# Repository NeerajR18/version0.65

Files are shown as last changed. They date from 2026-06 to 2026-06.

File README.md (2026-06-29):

# version0.65

version0.65 is an almost 65% keyboard. It is a bluetooth keyboard, using the SuperMini nRF52840 board, which is pin compatible with the nice!nano v2.
It has a built in battery along with a On/Off switch.

The keyboard is hotswap, with gateron hotswap sockets and Gateron Blue switches.

The PCB was designed in KiCad and the case was designed in Autodesk Fusion. The footprints for the switches have been taken from the marbastlib library - https://github.com/ebastler/marbastlib

This Keyboard was made for Hack Club KEEB.

Note: This is still a WIP. Please copy at your own risk.

## Repository Guide
```
version1/
|── PCB/
|   |── version0.65.kicad_pro
|   |── version0.65.kicad_pcb
|   |── version0.65.kicad_sch
|   └── fp-lib-table
|
|── CAD/
|   |── Base/
|   |   |── version0.65-base-left.step
|   |   |── version0.65-base-middle.step
|   |   └── version0.65-base-right.step
|   |   
|   |──── Top/
|   |     |── version0.65-plate-left.step
|   |     └── version0.65-plate-right.step
|   |
|   |── version0.65-assembly.step
|   └── version0.65.f3z
| 
|── Production/   
|    |── gerbers.zip/
|    |
|    |── STL Files/
|    |   |─── version0.65-base/
|    |   |    |── version0.65-base-left.stl
|    |   |    |── version0.65-base-middle.stl
|    |   |    └── version0.65-base-right.stl
|    |   |
|    |   └─── version0.65-plate/
|    |        |── version0.65-plate-left.stl
|    |        └── version0.65-plate-right.stl
|    |
|    └── STEP Files/
|           |─── version0.65-base/
|           |      |── version0.65-base-left.step
|           |      |── version0.65-base-middle.step
|           |      └── version0.65-base-right.step
|           |
|           └──── version0.65-plate/
|                   |── version0.65-plate-left.step
|                   └── version0.65-plate-right.step
|
|── Assets/
|    |── Keycaps/
|    |── MX Switch/
|    └── nice!nano/
|
|── Firmware/
|
|── BOM.csv
|── journal.md
└── README.md
```

## Schematic
##### Overall Schematic


## PCB
##### PCB Front without GND Plane


##### PCB Front with GND Plane


##### PCB Back without GND Plane


##### PCB Back with GND Plane


## CAD
The case has been split to accomodate 3D printing. The plates and base have small pegs and holes for assembly.

#### Full Assembly
##### Top View


#####  Side View


#### Top Plate
##### Top View


#####  Side View


#### Base
##### Top View


#####  Side View

 
## Firmware
version0.65 uses ZMK firmare. While the firmware has not been tested IRL, it can be found in a separate repository.

Firmware repository- https://github.com/NeerajR18/zmk-config-version0.65

## Bill of Materials
| Part Name | Quantity | Unit Price (USD) | Ext. Price (USD) | Link |
|---|---:|---:|---:|---|
| nRF52840 Development Board (Compatible with nice!nano) | 1 | 8.00 | 8.00 | https://robu.in/product/promicro-nrf52840-development-board/ |
| Gradient Keycaps | 1 | 13.66 | 13.66 | https://stackskb.com/store/veekos-gradient-keycaps-cherry-profile-135-keys/ |
| Gateron Hotswap Sockets | 66 | 0.11 | 7.00 | https://stackskb.com/store/gateron-hotswap-sockets/ |
| Gateron G Pro 3.0 Switch (Pack of 10) | 7 | 2.10 | 14.71 | https://meckeys.com/shop/accessories/keyboard-accessories/key-switches/gateron-g-pro-3-0-switch/ |
| OS102011MA1QN1 | 1 | 0.38 | 0.38 | https://robu.in/product/os102011ma1qn1-ck-100ma-single-pole-double-throw-spdt-12v-10000-times-plugin-slide-switches-rohs/ |
| S2B-PH-SM4-TB | 1 | 0.42 | 0.42 | https://robu.in/product/s2b-ph-sm4-tblfsn-jst-1x2p-2p-ph-tin-2-25%E2%84%8385%E2%84%83-2a-1-2mm-copper-alloy-horizontal-attachment-smdp2mmsurface-mount%EF%BC%8Cright-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 |
| 1N4148W-T4 | 66 | 0.015 | 0.99 | https://sharvielectronics.com/product/1n4148w-t4-high-speed-fast-switching-diode-sod-123-package/ |
| YY503040-JST-PH | 1 | 2.31 | 2.31 | https://sharvielectronics.com/product/3-7v-1100mah-lipo-rechargeable-battery-with-jst-ph-2mm-connector/ |
| PCB from Robu | 5 | 8.83 | 44.28 | https://robu.in/ |
| Cherry Stabilizer Set (GEON AND C3) | 1 | 7.36 | 7.36 | https://neomacro.in/products/cherry-stabilizer-set-geon-and-c3?_pos=3&_sid=9a6134911&_ss=r |
| M3 Heatset Insert | 20 | 0.025 | 0.50 | https://onlyscrews.in/products/m3-x-3mm-brass-threaded-inserts |
| M3 × 16mm Screws | 20 | 0.023 | 0.46 | https://onlyscrews.in/products/hex-allen-csk-m3-x-16-screw-pack-of-20 |
| Shipping charges |-| - | 7 | - |
| **Total** |  |  | **107.07** |  |

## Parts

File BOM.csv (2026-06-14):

Part Name | Quantity | Unit Price(USD) | Ext. Price (USD) | Link
nRF52840 Development Board(Compatible with nice!nano) | 1 | 8 | 8 | https://robu.in/product/promicro-nrf52840-development-board/
Gradient Keycaps | 1 | 13.66 | 13.66 | https://stackskb.com/store/veekos-gradient-keycaps-cherry-profile-135-keys/
Gateron Hotswap Sockets | 66 | 0.11 | 7 | https://stackskb.com/store/gateron-hotswap-sockets/
Gateron G Pro 3.0 Switch (Pack of 10) | 7 | 2.1 | 14.71 | https://meckeys.com/shop/accessories/keyboard-accessories/key-switches/gateron-g-pro-3-0-switch/
OS102011MA1QN1 | 1 | 0.38 | 0.38 | https://robu.in/product/os102011ma1qn1-ck-100ma-single-pole-double-throw-spdt-12v-10000-times-plugin-slide-switches-rohs/
S2B-PH-SM4-TB | 1 | 0.42 | 0.42 | https://robu.in/product/s2b-ph-sm4-tblfsn-jst-1x2p-2p-ph-tin-2-25%e2%84%8385%e2%84%83-2a-1-2mm-copper-alloy-horizontal-attachment-smdp2mmsurface-mount%ef%bc%8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
1N4148W-T4 | 66 | 0.015 | 0.99 | https://sharvielectronics.com/product/1n4148w-t4-high-speed-fast-switching-diode-sod-123-package/
Stabilizers set | 1 | 7.36 | 7.36 | https://neomacro.in/products/cherry-stabilizer-set-geon-and-c3?_pos=3&_sid=9a6134911&_ss=r
M3x3mm Heatset Inserts | 20 | 0.025 | 0.5 | https://onlyscrews.in/products/m3-x-3mm-brass-threaded-inserts
M3x16 mm Screws | 20 | 0.023 | 0.046 | https://onlyscrews.in/products/hex-allen-csk-m3-x-16-screw-pack-of-20
YY503040-JST-PH | 1 | 2.31 | 2.31 | https://sharvielectronics.com/product/3-7v-1100mah-lipo-rechargeable-battery-with-jst-ph-2mm-connector/
PCB from robu | 5 | 8.05 | 48.35 | https://robu.in/
Total |  |  | 103.726

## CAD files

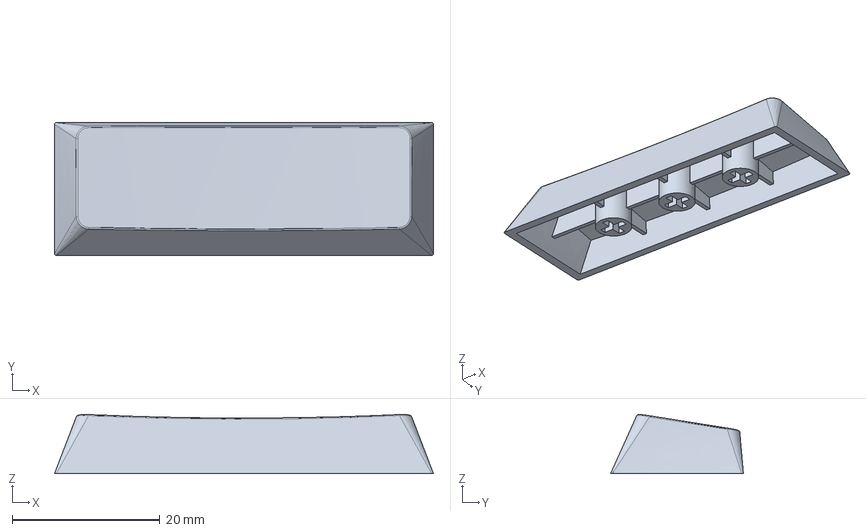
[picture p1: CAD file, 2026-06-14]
Assets/Keycaps/Rshift.step
51.3 x 18.0 x 8.00 mm

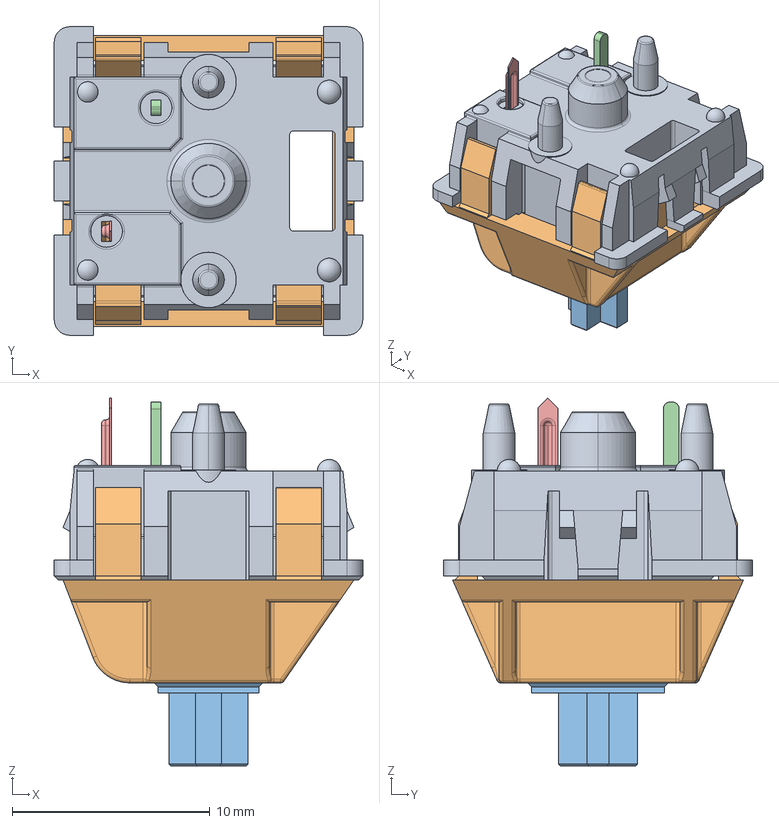
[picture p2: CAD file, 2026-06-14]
Assets/MX Switch/MX_switch.stp
15.6 x 15.6 x 18.6 mm
MX_DOWN
MX_UP
UP_MX
MX_PIN
MX_SPRING
MX_CLICK

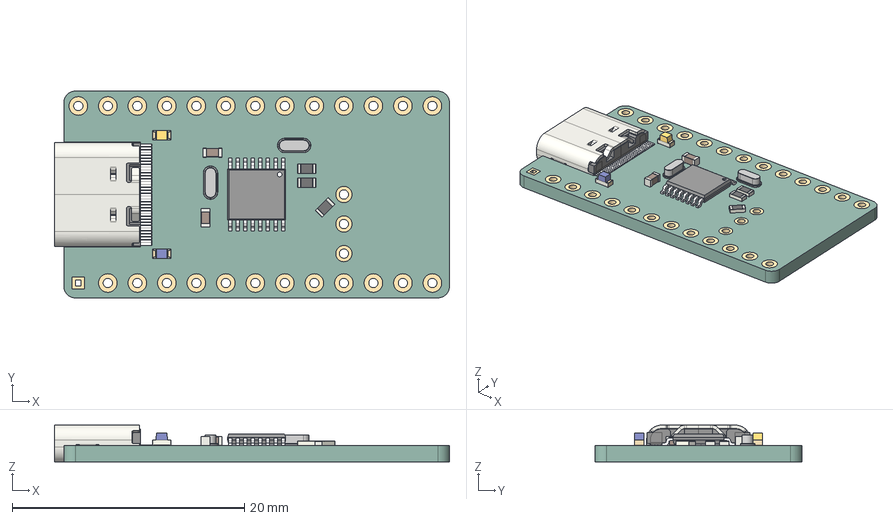
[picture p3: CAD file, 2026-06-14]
Assets/nice!nano/nice!nano v2.step
34.0 x 17.8 x 3.16 mm
nice!nano v1.0_1
USB_C_Receptacle_16P_TopMnt_Horizontal_GCT_USB4105-xx-A
USB_C_Receptacle_16P_TopMnt_Horizontal_GCT_USB4105-xx-A001
USB_C_Receptacle_16P_TopMnt_Horizontal_GCT_USB4105-xx-A002
USB_C_Receptacle_16P_TopMnt_Horizontal_GCT_USB4105-xx-A003
USB_C_Receptacle_16P_TopMnt_Horizontal_GCT_USB4105-xx-A004
USB_C_Receptacle_16P_TopMnt_Horizontal_GCT_USB4105-xx-A005
USB_C_Receptacle_16P_TopMnt_Horizontal_GCT_USB4105-xx-A006
USB_C_Receptacle_16P_TopMnt_Horizontal_GCT_USB4105-xx-A007
USB_C_Receptacle_16P_TopMnt_Horizontal_GCT_USB4105-xx-A008
USB_C_Receptacle_16P_TopMnt_Horizontal_GCT_USB4105-xx-A009
USB_C_Receptacle_16P_TopMnt_Horizontal_GCT_USB4105-xx-A010
USB_C_Receptacle_16P_TopMnt_Horizontal_GCT_USB4105-xx-A011
USB_C_Receptacle_16P_TopMnt_Horizontal_GCT_USB4105-xx-A012
USB_C_Receptacle_16P_TopMnt_Horizontal_GCT_USB4105-xx-A013
USB_C_Receptacle_16P_TopMnt_Horizontal_GCT_USB4105-xx-A014
USB_C_Receptacle_16P_TopMnt_Horizontal_GCT_USB4105-xx-A015
USB_C_Receptacle_16P_TopMnt_Horizontal_GCT_USB4105-xx-A016
USB_C_Receptacle_16P_TopMnt_Horizontal_GCT_USB4105-xx-A017
USB_C_Receptacle_16P_TopMnt_Horizontal_GCT_USB4105-xx-A018
USB_C_Receptacle_16P_TopMnt_Horizontal_GCT_USB4105-xx-A019
USB_C_Receptacle_16P_TopMnt_Horizontal_GCT_USB4105-xx-A020
USB_C_Receptacle_16P_TopMnt_Horizontal_GCT_USB4105-xx-A021
USB_C_Receptacle_16P_TopMnt_Horizontal_GCT_USB4105-xx-A022
USB_C_Receptacle_16P_TopMnt_Horizontal_GCT_USB4105-xx-A023
USB_C_Receptacle_16P_TopMnt_Horizontal_GCT_USB4105-xx-A024
USB_C_Receptacle_16P_TopMnt_Horizontal_GCT_USB4105-xx-A025
USB_C_Receptacle_16P_TopMnt_Horizontal_GCT_USB4105-xx-A026
USB_C_Receptacle_16P_TopMnt_Horizontal_GCT_USB4105-xx-A027
USB_C_Receptacle_16P_TopMnt_Horizontal_GCT_USB4105-xx-A028
USB_C_Receptacle_16P_TopMnt_Horizontal_GCT_USB4105-xx-A029
USB_C_Receptacle_16P_TopMnt_Horizontal_GCT_USB4105-xx-A030
USB_C_Receptacle_16P_TopMnt_Horizontal_GCT_USB4105-xx-A031
USB_C_Receptacle_16P_TopMnt_Horizontal_GCT_USB4105-xx-A032
USB_C_Receptacle_16P_TopMnt_Horizontal_GCT_USB4105-xx-A033
USB_C_Receptacle_16P_TopMnt_Horizontal_GCT_USB4105-xx-A034
USB_C_Receptacle_16P_TopMnt_Horizontal_GCT_USB4105-xx-A035
Pin9
Pin10
Pin12
Pin11
Pin13
Pin14
Pin15
Pin16
Pin8
Pin7
Pin6
Pin5
Pin4
Pin3
Pin2
Pin1
LED_0603_1608Metric_ON
C_0603_1608Metric x 2
LED_0603_1608Metric_ON_1
Crystal Oscillator x 2
R_0603_1608Metric x 4

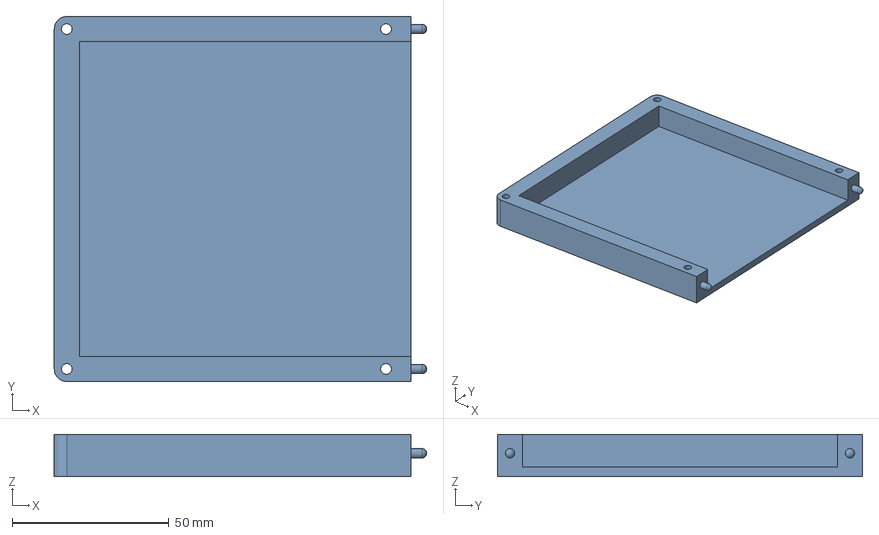
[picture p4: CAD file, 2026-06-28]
CAD/Base/version0.65-base-left.step
118.8 x 116.4 x 13.4 mm

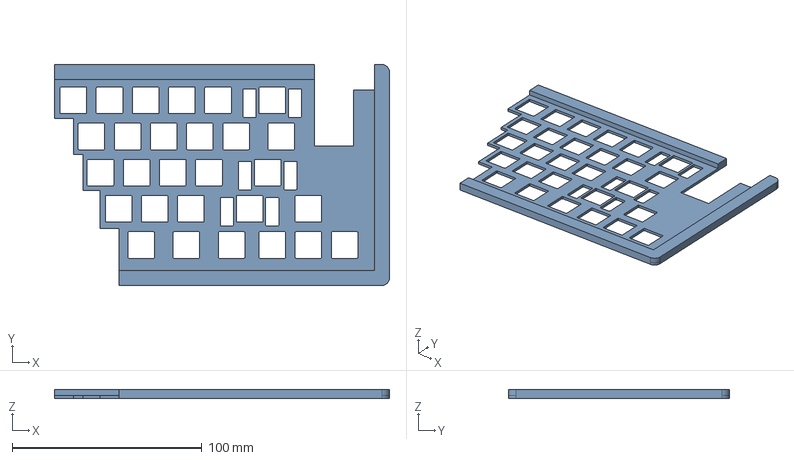
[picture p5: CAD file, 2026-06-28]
CAD/Plate/version0.65-plate-right.step
176.5 x 116.4 x 4.50 mm

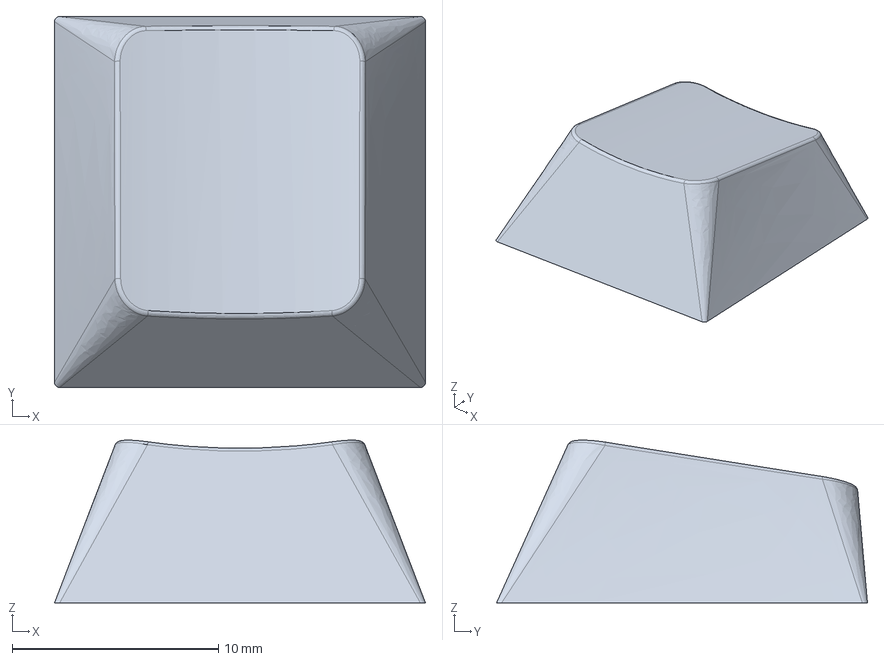
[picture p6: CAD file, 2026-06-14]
Assets/Keycaps/Qwerty.step
18.0 x 18.0 x 7.90 mm

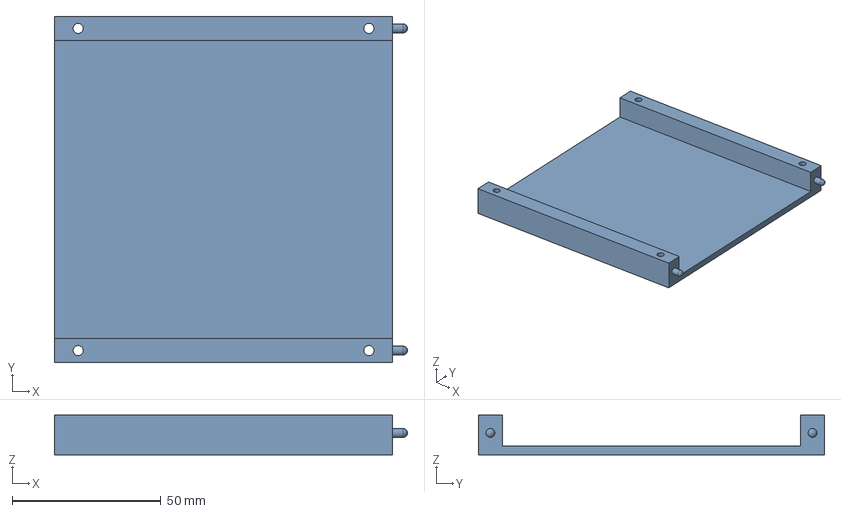
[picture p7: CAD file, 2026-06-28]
CAD/Base/version0.65-base-middle.step
118.8 x 116.4 x 13.4 mm

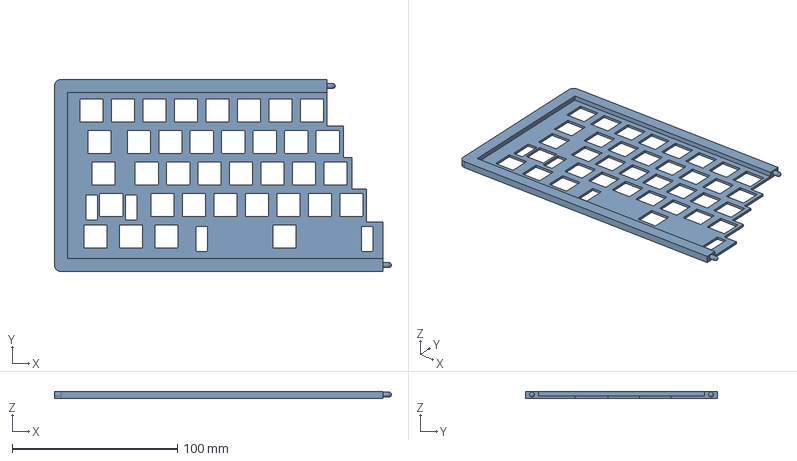
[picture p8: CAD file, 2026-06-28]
CAD/Plate/version0.65-plate-left.step
204.0 x 116.4 x 4.50 mm

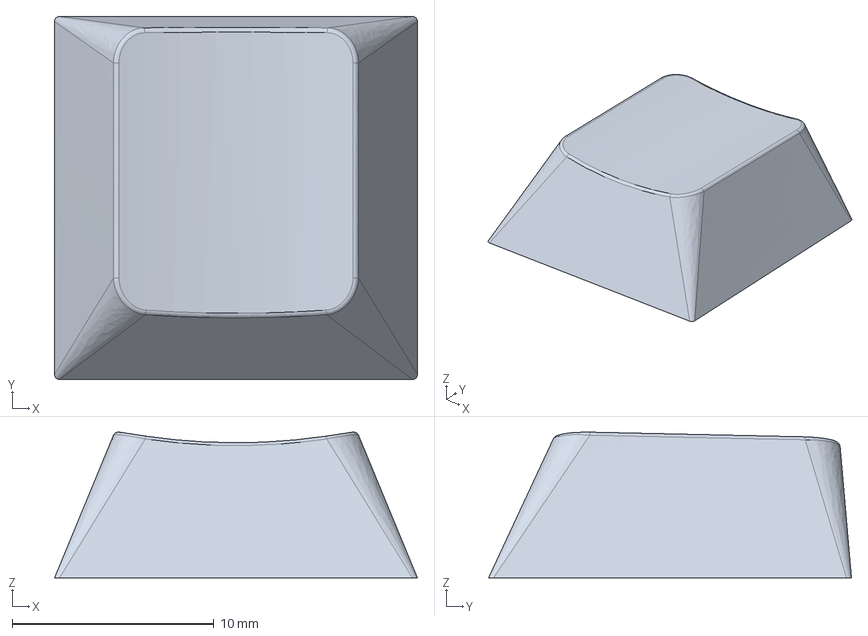
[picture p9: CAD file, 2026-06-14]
Assets/Keycaps/ROW_1_Numbers.step
18.0 x 18.0 x 7.23 mm

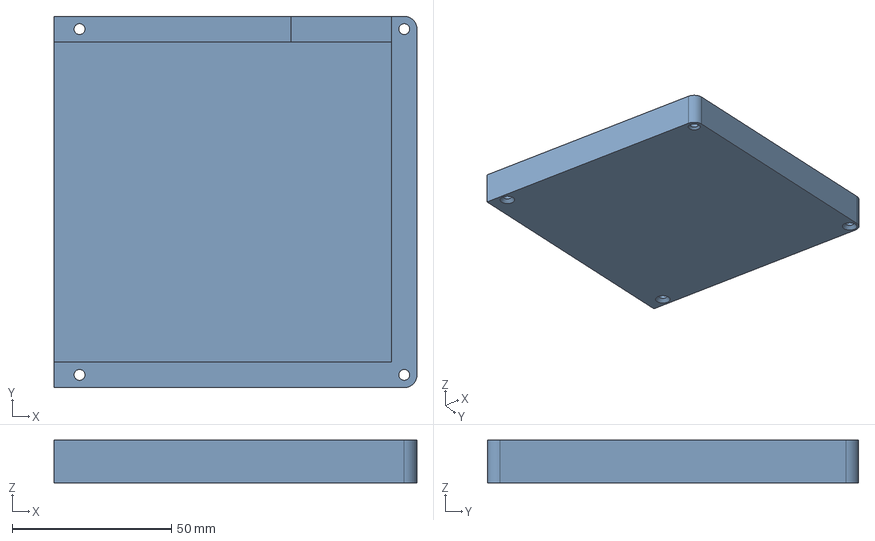
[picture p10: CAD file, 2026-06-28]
CAD/Base/version0.65-base-right.step
113.8 x 116.4 x 13.4 mm

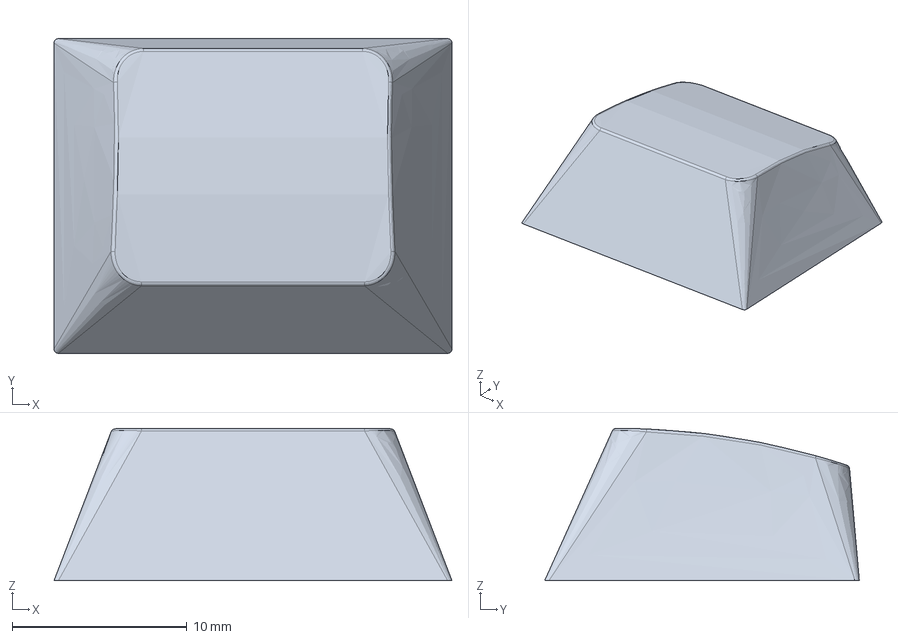
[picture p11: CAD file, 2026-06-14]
Assets/Keycaps/Bottom_row1u25.step
22.8 x 18.0 x 8.70 mm

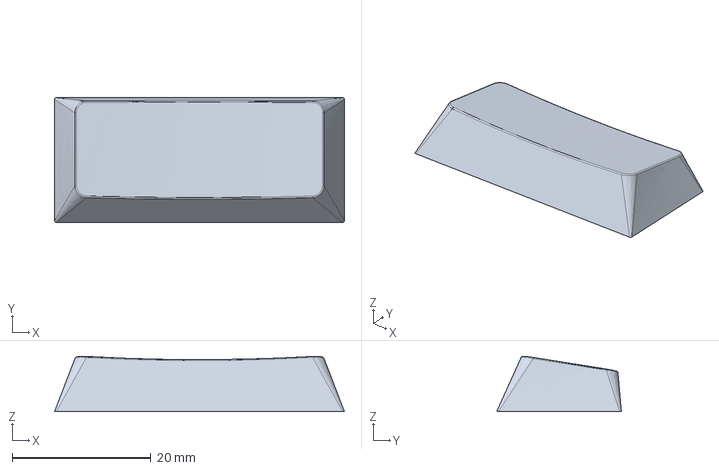
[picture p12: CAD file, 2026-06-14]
Assets/Keycaps/Enter_Lshift.step
41.8 x 18.0 x 7.99 mm

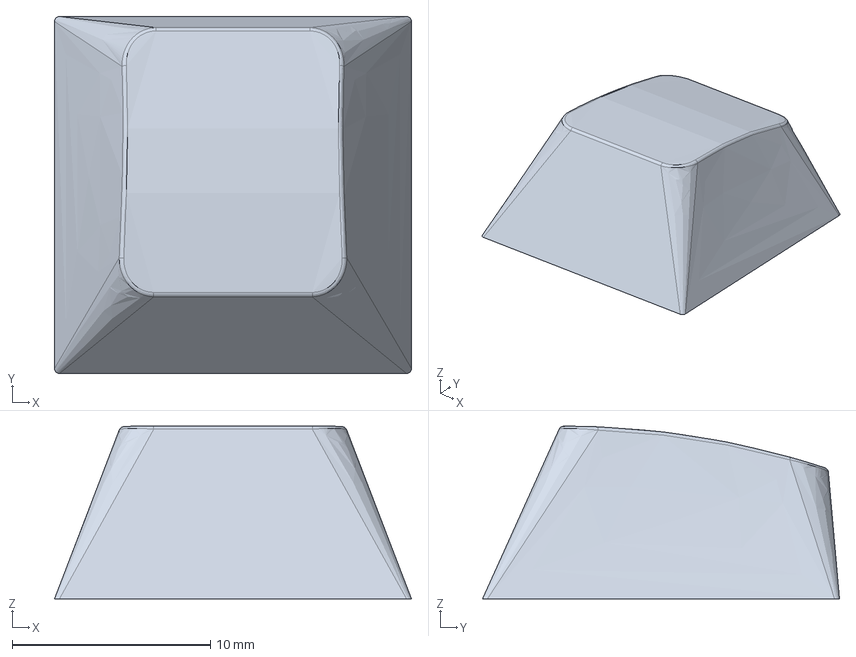
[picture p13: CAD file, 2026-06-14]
Assets/Keycaps/Bottom_row1u.step
18.0 x 18.0 x 8.70 mm

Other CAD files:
Assets/Keycaps/Back_sp.step
Assets/Keycaps/Backsp.step
Assets/Keycaps/Caps.step
Assets/Keycaps/ESC_and_Function_keys.step
Assets/Keycaps/Space_bar.step
Assets/Keycaps/Tab_key.step
Assets/Keycaps/middle_row.step
Production/STL Files/Base/version0.65-base-left.stl
Production/STL Files/Base/version0.65-base-middle.stl
Production/STL Files/Base/version0.65-base-right.stl
Production/STL Files/Plate/version0.65-plate-left.stl
Production/STL Files/Plate/version0.65-plate-right.stl

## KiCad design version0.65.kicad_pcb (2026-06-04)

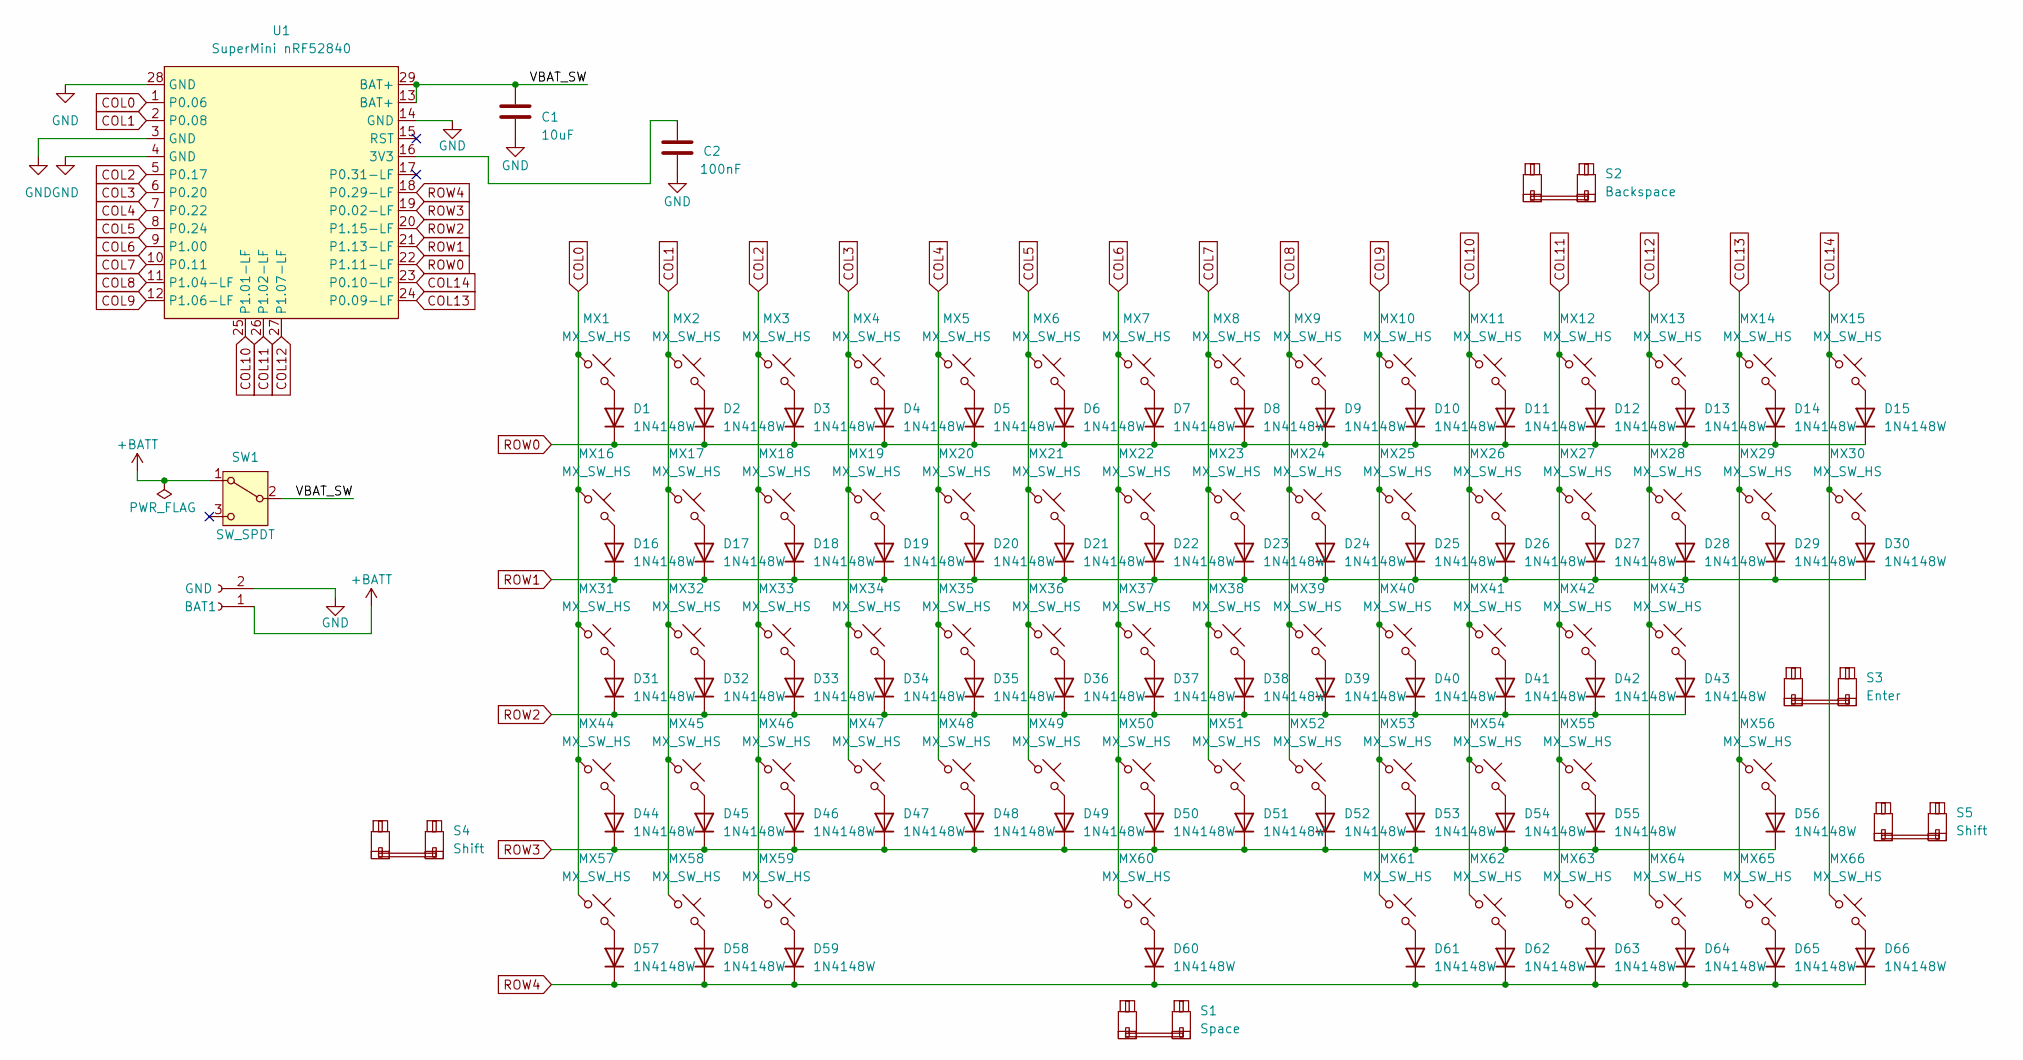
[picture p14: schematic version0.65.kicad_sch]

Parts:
BAT1: GND; JST_PH_S2B-PH-K_1x02_P2.00mm_Horizontal
C1: 10uF; C_0805_2012Metric
C2: 100nF; C_0805_2012Metric
D1, D2, D3, D4, D5, D6, D7, D8, D9, D10, D11, D12, D13, D14, D15, D16, D17, D18, D19, D20, D21, D22, D23, D24, D25, D26, D27, D28, D29, D30, D31, D32, D33, D34, D35, D36, D37, D38, D39, D40, D41, D42, D43, D44, D45, D46, D47, D48, D49, D50, D51, D52, D53, D54, D55, D56, D57, D58, D59, D60, D61, D62, D63, D64, D65, D66: 1N4148W; D_SOD-123
MX1, MX2, MX3, MX4, MX5, MX6, MX7, MX8, MX9, MX10, MX11, MX12, MX13, MX14, MX15, MX17, MX18, MX19, MX20, MX21, MX22, MX23, MX24, MX25, MX26, MX27, MX28, MX30, MX32, MX33, MX34, MX35, MX36, MX37, MX38, MX39, MX40, MX41, MX42, MX43, MX44, MX45, MX46, MX47, MX48, MX49, MX50, MX51, MX52, MX53, MX54, MX55, MX56, MX58, MX60, MX64, MX65, MX66: MX_SW_HS; SW_MX_HS_KS-2P02B01-01_1u
MX16, MX29: MX_SW_HS; SW_MX_HS_KS-2P02B01-01_1.5u
MX31: MX_SW_HS; SW_MX_HS_KS-2P02B01-01_1.75u
MX57, MX59, MX61, MX62, MX63: MX_SW_HS; SW_MX_HS_KS-2P02B01-01_1.25u
S1: Space; STAB_MX_P_6.25u
S2: Backspace; STAB_MX_2u
S3: Enter; STAB_MX_2.25u
S4, S5: Shift; STAB_MX_2.25u
SW1: SW_SPDT; SW_Slide_SPDT_Angled_CK_OS102011MA1Q
U1: SuperMini nRF52840; SuperMini_nRF52840_AH_USBup

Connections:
+BATT: BAT1.1, SW1.1 (A)
/VBAT_SW: C1.2, SW1.2 (B), U1.13 (BAT+), U1.29 (BAT+)
COL0: MX1.1, MX16.1, MX31.1, MX44.1, MX57.1, U1.1 (P0.06)
COL1: MX2.1, MX17.1, MX32.1, MX45.1, MX58.1, U1.2 (P0.08)
COL2: MX3.1, MX18.1, MX33.1, MX46.1, MX59.1, U1.5 (P0.17)
COL3: MX4.1, MX19.1, MX34.1, MX47.1, U1.6 (P0.20)
COL4: MX5.1, MX20.1, MX35.1, MX48.1, U1.7 (P0.22)
COL5: MX6.1, MX21.1, MX36.1, MX49.1, U1.8 (P0.24)
COL6: MX7.1, MX22.1, MX37.1, MX50.1, MX60.1, U1.9 (P1.00)
COL7: MX8.1, MX23.1, MX38.1, MX51.1, U1.10 (P0.11)
COL8: MX9.1, MX24.1, MX39.1, MX52.1, U1.11 (P1.04-LF)
COL9: MX10.1, MX25.1, MX40.1, MX53.1, MX61.1, U1.12 (P1.06-LF)
COL10: MX11.1, MX26.1, MX41.1, MX54.1, MX62.1, U1.25 (P1.01-LF)
COL11: MX12.1, MX27.1, MX42.1, MX55.1, MX63.1, U1.26 (P1.02-LF)
COL12: MX13.1, MX28.1, MX43.1, MX64.1, U1.27 (P1.07-LF)
COL13: MX14.1, MX29.1, MX56.1, MX65.1, U1.24 (P0.09-LF)
COL14: MX15.1, MX30.1, MX66.1, U1.23 (P0.10-LF)
GND: BAT1.2, C1.1, C2.1, U1.3 (GND), U1.4 (GND), U1.14 (GND), U1.28 (GND)
unnamed: D1.2 (A), MX1.2
unnamed: D2.2 (A), MX2.2
unnamed: D3.2 (A), MX3.2
unnamed: D4.2 (A), MX4.2
unnamed: D5.2 (A), MX5.2
unnamed: D6.2 (A), MX6.2
unnamed: D7.2 (A), MX7.2
unnamed: D8.2 (A), MX8.2
unnamed: D9.2 (A), MX9.2
unnamed: D10.2 (A), MX10.2
unnamed: D11.2 (A), MX11.2
unnamed: D12.2 (A), MX12.2
unnamed: D13.2 (A), MX13.2
unnamed: D14.2 (A), MX14.2
unnamed: D15.2 (A), MX15.2
unnamed: D16.2 (A), MX16.2
unnamed: D17.2 (A), MX17.2
unnamed: D18.2 (A), MX18.2
unnamed: D19.2 (A), MX19.2
unnamed: D20.2 (A), MX20.2
unnamed: D21.2 (A), MX21.2
unnamed: D22.2 (A), MX22.2
unnamed: D23.2 (A), MX23.2
unnamed: D24.2 (A), MX24.2
unnamed: D25.2 (A), MX25.2
unnamed: D26.2 (A), MX26.2
unnamed: D27.2 (A), MX27.2
unnamed: D28.2 (A), MX28.2
unnamed: D29.2 (A), MX29.2
unnamed: D30.2 (A), MX30.2
unnamed: D31.2 (A), MX31.2
unnamed: D32.2 (A), MX32.2
unnamed: D33.2 (A), MX33.2
unnamed: D34.2 (A), MX34.2
unnamed: D35.2 (A), MX35.2
unnamed: D36.2 (A), MX36.2
unnamed: D37.2 (A), MX37.2
unnamed: D38.2 (A), MX38.2
unnamed: D39.2 (A), MX39.2
unnamed: D40.2 (A), MX40.2
unnamed: D41.2 (A), MX41.2
unnamed: D42.2 (A), MX42.2
unnamed: D43.2 (A), MX43.2
unnamed: D44.2 (A), MX44.2
unnamed: D45.2 (A), MX45.2
unnamed: D46.2 (A), MX46.2
unnamed: D47.2 (A), MX47.2
unnamed: D48.2 (A), MX48.2
unnamed: D49.2 (A), MX49.2
unnamed: D50.2 (A), MX50.2
unnamed: D51.2 (A), MX51.2
unnamed: D52.2 (A), MX52.2
unnamed: D53.2 (A), MX53.2
unnamed: D54.2 (A), MX54.2
unnamed: D55.2 (A), MX55.2
unnamed: D56.2 (A), MX56.2
unnamed: D57.2 (A), MX57.2
unnamed: D58.2 (A), MX58.2
unnamed: D59.2 (A), MX59.2
unnamed: D60.2 (A), MX60.2
unnamed: D61.2 (A), MX61.2
unnamed: D62.2 (A), MX62.2
unnamed: D63.2 (A), MX63.2
unnamed: D64.2 (A), MX64.2
unnamed: D65.2 (A), MX65.2
unnamed: D66.2 (A), MX66.2
unnamed: C2.2, U1.16 (3V3)
ROW0: D1.1 (K), D2.1 (K), D3.1 (K), D4.1 (K), D5.1 (K), D6.1 (K), D7.1 (K), D8.1 (K), D9.1 (K), D10.1 (K), D11.1 (K), D12.1 (K), D13.1 (K), D14.1 (K), D15.1 (K), U1.22 (P1.11-LF)
ROW1: D16.1 (K), D17.1 (K), D18.1 (K), D19.1 (K), D20.1 (K), D21.1 (K), D22.1 (K), D23.1 (K), D24.1 (K), D25.1 (K), D26.1 (K), D27.1 (K), D28.1 (K), D29.1 (K), D30.1 (K), U1.21 (P1.13-LF)
ROW2: D31.1 (K), D32.1 (K), D33.1 (K), D34.1 (K), D35.1 (K), D36.1 (K), D37.1 (K), D38.1 (K), D39.1 (K), D40.1 (K), D41.1 (K), D42.1 (K), D43.1 (K), U1.20 (P1.15-LF)
ROW3: D44.1 (K), D45.1 (K), D46.1 (K), D47.1 (K), D48.1 (K), D49.1 (K), D50.1 (K), D51.1 (K), D52.1 (K), D53.1 (K), D54.1 (K), D55.1 (K), D56.1 (K), U1.19 (P0.02-LF)
ROW4: D57.1 (K), D58.1 (K), D59.1 (K), D60.1 (K), D61.1 (K), D62.1 (K), D63.1 (K), D64.1 (K), D65.1 (K), D66.1 (K), U1.18 (P0.29-LF)

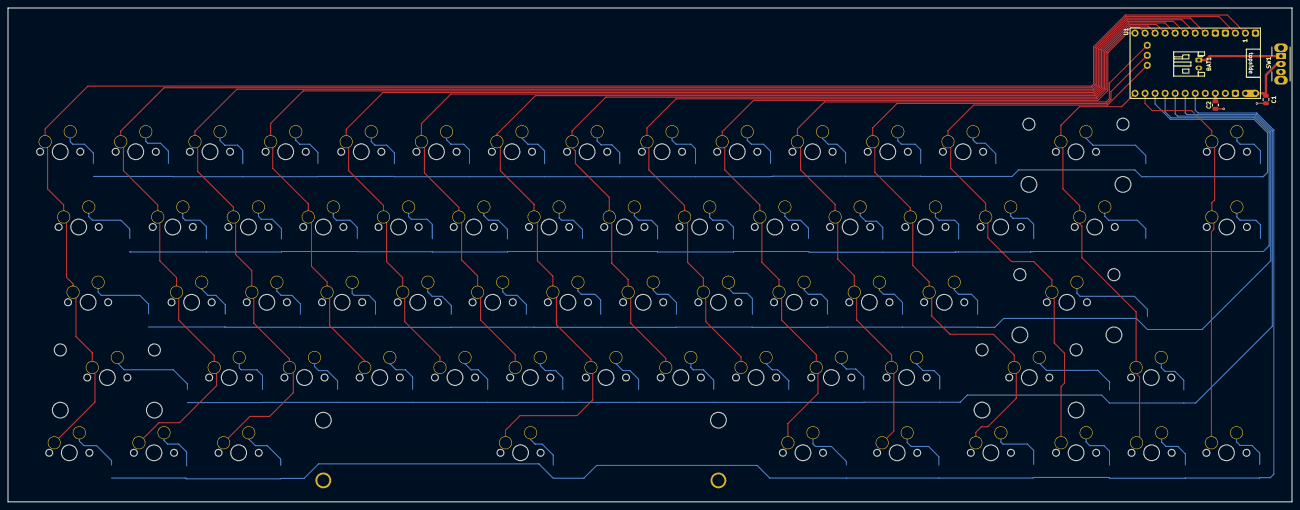
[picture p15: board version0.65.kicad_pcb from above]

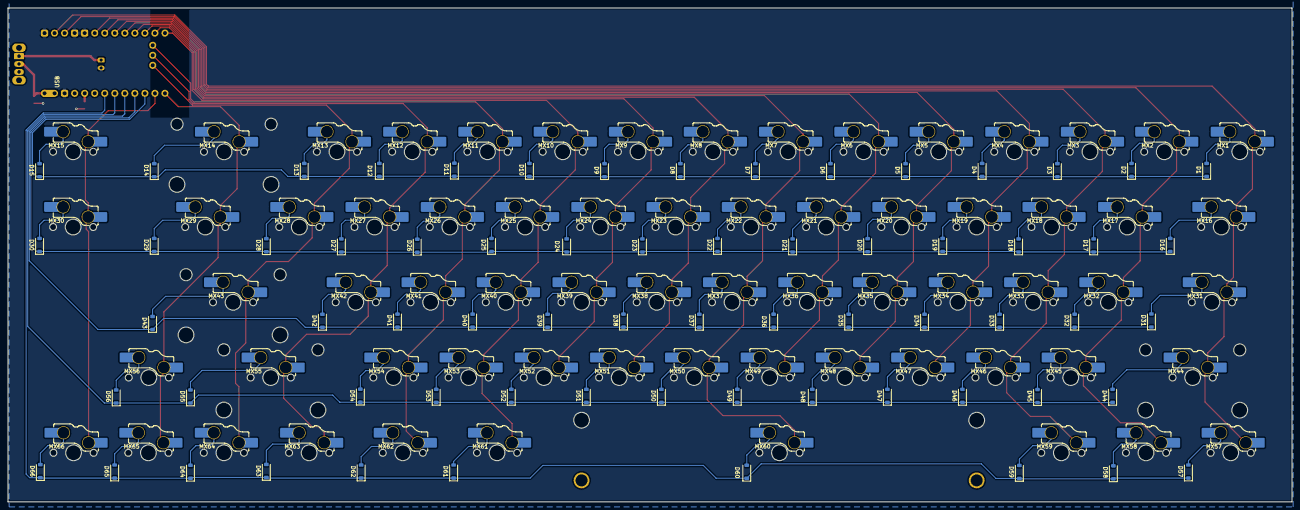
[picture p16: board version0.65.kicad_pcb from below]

Board: 2 copper layers, 325.0 x 125.0 mm, 142 parts (133 on the bottom side), 90 nets.

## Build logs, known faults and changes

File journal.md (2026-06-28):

## Journal 1

I started my first project for KEEB!

I have decided to make a Leopold 660m layout keyboard, a wireless keyboard with the Supermini nrF52840.
Now, I had to find some reference keyboards since I have not used the Supermini or made a wireless keyboard.
I found a great project on a 65% keyboard. It uses through hole components but that is not a big problem, since I know how the matrix and connections work. I only needed to refer to the battery connections and the GPIOs I can use.
This is the reference I found : https://github.com/RafaelCasamaximo/voidPointer
This is a really great project in my opinion and since it was already built, it was even more helpful.
All I had to do now was make the schematic, assign the footprints and start building!

I like minimal keyboards, so I have only the keys, the supermini and a sandwich mount case (or integrated plate) case.
The repo I was referring to also had a slider switch, which was pretty cool!
I added all the components, and placed them according to the reference.
I also had fewer switches compared to the reference, so I made some changes to the matrix.

While I do not have all the images of my schematic building process, I do have the full schematic ready. 
I am using Gateron hotswap sockets for this keyboard, along with SOD-123 diodes. All my footprints are from the marbastlib library(along with supermini)



I assigned footprints and now I have to place all the components.
For this, I used the grid from the guide,and the generated plate from the ai03 plate generator.

#### Time taken - around 2 hrs to make the schematic and place all switches.

## Journal 2

Today, I did the entire PCB layout!
This is my favourite part of the entire PCB design because it really gets me thinking because of constant changes to the layout and I get to crashout.



I had already laid down the keys, so all I had to do was routing. I had also not laid out the diodes and added the stabilizers correctly. The Leopold does not have a very long right shift so, I had to change those, and also while updating the schematic, some of the footprints were changed only in the PCB editor, which caused it to change.
I fixed everything, then I decided that the top right of the PCB is the best placed for the supermini. It increases the height a bit, but yes, that is inevitable imo but it is also almost equivalent to the size of the Leopold 660m(with case but yes since this is custom, I have my say ;D )

This is how the keyboard looked after I placed the diodes.



Now, routing is always a challenge with the matrix, as it can be optimised in such a way that there is no need for vias and it looks clean.
I had to change the pins many times while routing this.
I routed all the diodes first. I have my own way of routing diodes so that it passes with some gap with the holes.
Sure, the normal way is fine but there is always a risk.



Here are some images of the PCB routing process-



This was the first routing layout I did. The GPIOs were unreachable and the traces were too far apart, increasing the width of the PCB.
I changed this.

I changed my pins a few more times and reached to this layout. All that was left were the ground connections and battery connections.
I added the battery connections.


I then added a ground plane on both sides to finish the PCB. I also made the edge.cuts to finalise the board edges.
This is how it looks.


DRC was run, and no errors occured!
I need to add some silkscreen, and add keycaps and switches to the PCB to move to CAD.

#### Time taken - around 2.5 hours to finish up the PCB routing, remaining layout etc. (I also changed many things in the schematic for the PCB, thus the long time.)

## Journal 3 

Now, I started by adding the keycaps. Since I have already done a PCB design, I had a easy way to add the switches and keycaps, by taking the x,y,z and angle values and noting them and directly plugging them in. This is also a fun but time taking part
This is how the first keycap looks-



KiCad crashed on me once today while adding the keycaps

Here is me adding the backspace keycap


This is some tiresome work, but here is the PCB after I added half of the keycaps


And the last keycap 


This is how the PCB looks 


#### Time taken - 50 minutes to manually add and align all switches and keycap models.

## Journal 4

I started CAD today. I have decided for a sandwich mount case. I also will leave out the space for the devboard.

I imported the the .step of the PCB from KiCad to Fusion.



Then, I made a sketch to make the base.
The base was made to have 8mm thick walls on each side.



I then extruded only the base under the pcb. 



Then I made the walls and aligned it to the Top edges of the PCB





I then imported the plate.dxf from ai03's plate generator 


I then aligned the plate to the keycaps, extruded the sides to match the entire base length.





This was the case halfway done.


I then made the top part of the sandwich from the same sketch I used for the walls.



Finally, I ended up with this



I made the holes for countersunk hex screws.




I added the screws in Fusion.



#### Time taken- around 2 hours for entire case design.

## Journal 5
While the earlier case will work, hobbyist 3d printing cannot accomodate such large sizes. So, to counter this, I designed another case of the same layout, split in 3 pieces in the base and a top with 2 pieces, making an integrated plate case.

I started with a new sketch with same measurements.


I extruded all the base parts one by one


Next, the walls 


Aligned everything.


I imported the plate and then extruded it and aligned it with the switches.


Then extruded the sides to complete the plate.


After fixing the walls, this is how the case looked.



I then added the extruded the top part


I cleaned up everything, made the cutout for the nice!nano.
I added colors to the keyboard and the color scheme I am going for.


Then I added holes for the screws


Inserted screws



For the split case, I also added small tab like structures to help for structural integrity


And done!

#### Time taken - around 1.5 hours for split case design. 

## Journal 6
I made the firmware for the keyboard. I am using ZMK, which is pretty new to me and so are bluetooth keyboards.
This was a pretty huge task. I first set up ZMK on my device using the docs.


After this, I edited the keymaps and all config files, and made the .uf2 file.
The firmware itself was pretty easy to do but the configuration and manual assignment was pretty slow from my side, and I had to keep verifying it.
It took me 9 commits to fix the errors to build the .uf2 file.
Anyways, I am ready to submit. I have also made the BOM and repo.

#### Time taken- around 1.5 hours for firmware.

## Journal 7 

I made some changes to the PCB. I removed the two extra keys, which opened up some space for the microcontroller board. 
This kept the width same but height reduced to 100mm.
I changed the scehmatic accordingly.

I decided to reroute the PCB from scratch.

I first started with the rows

Then connected the diodes

After that, all the column pins were connected.

I then connected everything to the devboard.

Now this took me some time because the spacing and clearances had to be looked after, and the traces had to travel a lot.
The column pins went through many regions, including below the spacebar between row routing etc.
It was fun to do.
I finally added a GND plane

DRC also did not give any errors.

#### Time taken- around 1.5 hours for redoing the PCB from the start.

## Journal 8

Since, I changed my PCB, my case will also have to be changed. So, I did that.
I first imported my PCB step file from KiCad to Fusion

After that, I made a sketch for the base (split).

I extruded 3mm to make the base.

I then extruded the walls.

After this, I imported the plate.dxf and then split that into two parts.

I extruded one part and aligned it with the switches

I did the same with the other part

I then extruded all the edges to match the base.

I then made the sketch for the extrusion for the top part.

Combined it

I did the same steps for the other parts and added some fillets.

After that, I made the sketch for the MCU board.

Then I cut the portion

Added the color scheme

Made Holes for the screws,

Added screws.

and done!

#### Time taken- around 2 hours for redoing the case.

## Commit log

2026-06-05 Added 3D models to PCB and journal.md without images
2026-06-14 Added PCB and CAD files along with gerbers
    [version0.65-base.step, version0.65-plate.step, version0.65-top.step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]
2026-06-14 Added Production Files, BOM, Assets and CAD files
    [BOM.csv, Back_sp.step, Backsp.step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]
2026-06-28 Updated PCB files
    [version0.65.kicad_sch]
2026-06-28 Document PCB and case redesign in journal
2026-06-28 Revise CAD folder structure and update images
2026-06-28 Updated CAD Files and stl files for production
    [version0.65-base-left.step, version0.65-base-left.stl, version0.65-base-middle.step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]
2026-06-29 Update README.md with PCB images and BOM
